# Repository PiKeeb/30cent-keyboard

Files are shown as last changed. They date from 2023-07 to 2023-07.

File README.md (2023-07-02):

# 30cent-keyboard





**30Cent** or **30₡** is a unique modular multi-layout ortholinear keyboard with *south-facing* MX sockets. It combines the functionalities of 30%, 40%, and 60% keyboards, allowing users to customize their layout. By removing the top and bottom rows, the keyboard can be transformed from a 5-row layout to a 4-row or 3-row layouts.Alternatively, users can keep the full layout intact to resemble a 60% keyboard, featuring a unique top row, that can be mounted either flat or at an angle.

The top row of the keyboard features two independent rotary encoders, eight function keys (or ten without the encoders), and a 0.91" I²C screen. The screen can be used to display various information, such as a WPM counter for typing speed.

The bottom row of the keyboard supports multiple space configurations. Users can choose between ultra-long options like 10U and 7U, or go with the standard 6.25U size. Additionally, there is a split configuration available, which consists of 1.50U + 2.25U + 2.25U + 1.50U.

Furthermore, the keyboard offers the flexibility to attach the top row at an angle using a FFC (Flexible Flat Cable), resulting in a truly unique and compact keyboard design.

## Features
- **Multi-layout Design**: Combines the functionalities of 30%, 40%, and 60% keyboards, allowing for versatile customization of the keyboard layout.
- **Breakable Top and Bottom Rows**: The ability to break off the top and bottom rows, transforming the keyboard from a forty-key layout to a thirty-key layout.
- **Unique Top Row**: Retains a unique top row even when the full layout is intact, providing a distinct design element.
- **Dual Rotary Encoders**: Supports two independent encoders on the top row for enhanced control and customization.
**Function Keys**: Features eight function keys (or ten without the knobs) for convenient access to additional commands.
**0.91" I²C Screen**: Top row includes a 0.91" I²C screen for displaying various information, such as a WPM counter for typing speed.
- **Multiple Space Configuration**s: Offers options for the bottom row space, including ultra-long configurations (10U and 7U), standard 6.25U, and a split configuration (1.50U + 2.25U + 2.25U + 1.50U). Additionally, users have the option to use two 2U keys as spaces if the bottom row is not being utilized.
- **Angled Top Row Attachment**: Provides the ability to attach the top row at an angle using a Flexible Flat Cable (FFC), resulting in a unique keyboard design.
- **MX Sockets**: Compatible with MX sockets, allowing for easy switch customization and replacement.
- **Optional Key Backlighting**: Offers the option for key backlighting, enhancing visibility and aesthetics in low-light environments.
- **Unique Breakable PCB Design**: The PCB is designed to be breakable, allowing for easy detachment and reattachment of top and bottom rows, facilitating customization of the keyboard layout.

## 3D CAD Renders

30CentRender 1
30CentRender 2
30CentRender 3
30CentRender 4

## Disclaimers

All the designs and files are provided **"AS IS"** without any warranty or support.

The designs are licensed under [**CC BY-SA 4.0 International Licence**](https://creativecommons.org/licenses/by-sa/4.0/)

**Warning!** This project has not been prototyped as of right now (working on it). Bear that in mind when doing anything with it.

## Project's Folder Structure

- `/case_files` contains the files related to the case design
- `/plate_files` contains the files related to the plate design
- `/pcb_files` contains the files related to the PCB design

Each subfolder contains `README.md` file that is useful to read if you'd like to produce or modify the project

## Acknowledgements

- PCB designed in [KiCad](https://www.kicad.org)
- Case designed and rendered in [Fusion360](https://www.autodesk.com/products/fusion-360/overview)
- The design inspired by Rotwitt's original [Modul concept/idea](https://media.discordapp.net/attachments/999745796532604949/1011554374352379954/SE.png)

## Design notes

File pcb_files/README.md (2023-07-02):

# 30cent-keyboard/pcb_files

## Folder Structure

- `/bom` contains the Bill of Material for PCB in interactive HTML format
- `/gerber` contains the Gerber files for PCB production
- `/kicad_project` contains the KiСad project files
- `/pcb_3dmodel` contains STEP 3D model of the PCB

**NB:** for opening the project files use the following version of KiCad (or newer):

*Version: 7.0.1-0, release build*

## PCB Revision History

REV  |  Description
--|--
1.0  |  Open-source Release version

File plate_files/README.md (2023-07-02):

# 30cent-keyboard/plate_files

## Folder Structure

- `/dxf` contains the DXF drawings of the key plates 
- `/step` contains STEP 3D models of the key plates

## Production instructions

All key plates have standart 1.5mm thickness.

`MidPlate` and `TopPlate` and `BotPlateCombined` are layout-agnostic. However, due to the location of stabilizer and switch holes, it's recommended to use `BotPlate*` tailored to your specific bottom row layout. If for example you'd like to use the **10U** spacebar, use the `BotPlate10.00u`.

You can omit the `BotPlate*` and/or the `TopPlate` if you don't plan to use bottom and/or top row(s).

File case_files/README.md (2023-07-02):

# 30cent-keyboard/case_files

## Production Instructions

### File Naming Convention

Due to modular nature, 30Cent keyboard has many parts. Each part corresponds to either the top, middle or bottom module of the keyboard.

`MiddleBody` is the center part of the assembly.

Parts that start with `Middle*` attach to the `MiddleBody` to form 30% layout.

Parts that start with `Top*` or `Bottom*` are used to attach the top and bottom rows respectively.

### Case Threads

ALL the threads on the case are standard M2.5. Threads should go inside the holes as deep as possible.

Thread locations for each part are below.

- MiddleBody
MiddleBodyT
MiddleBodyB

- TopBottom
TopAngle

- TopAngle
AngleTop

- TopTop
TopTop

- BottomTop
LongBottom

- MiddleTopSide x 2
MiddleTopSides

- MiddleUSBTop & MiddleBottomTop
MiddleUSBTopAndBottom

## Screw table

Below is the table containing all the screws needed for the assembly of the keyboard. 

Screw Type | Size | Length (mm) | McMaster P/N | Quantity
---------- | ---- | ----------- | ------------ | --------
ISO 14581  | M2.5 | 3	        | 90236A109    | 14
ISO 7380   | M2.5 | 6           | 92832A174    | 6
ISO 14581  | M2.5 | 10          | 90236A113    | 8
ISO 7380   | M2.5 | 12          | 92832A562    | 31

They are replacable with similar sized screws. 

**Warning!** When choosing similar screws, make sure that the nominal head diameter does exceed 4.7mm.

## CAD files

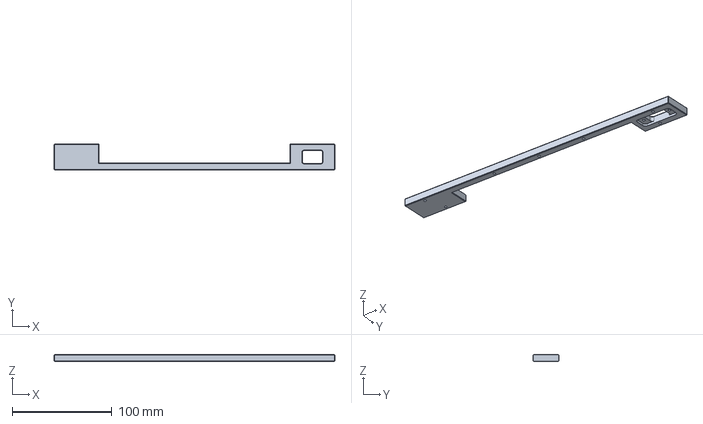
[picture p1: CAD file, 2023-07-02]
case_files/BottomTop.step
281.1 x 26.0 x 7.00 mm

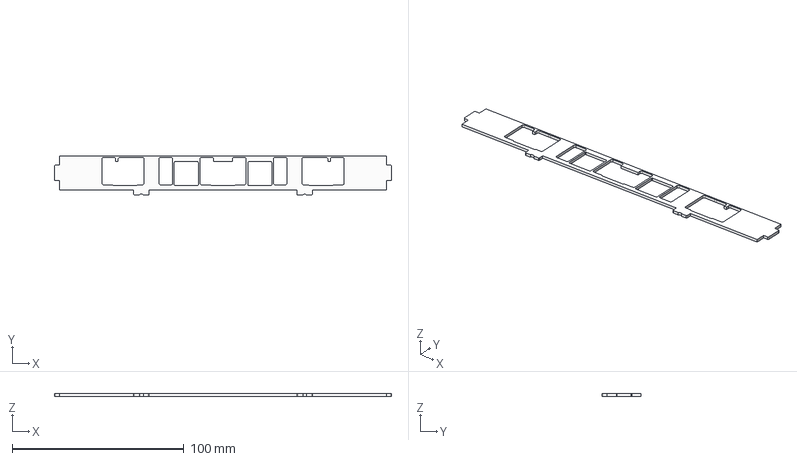
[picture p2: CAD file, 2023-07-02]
plate_files/step/BotPlateCombined.step
196.5 x 22.8 x 1.50 mm

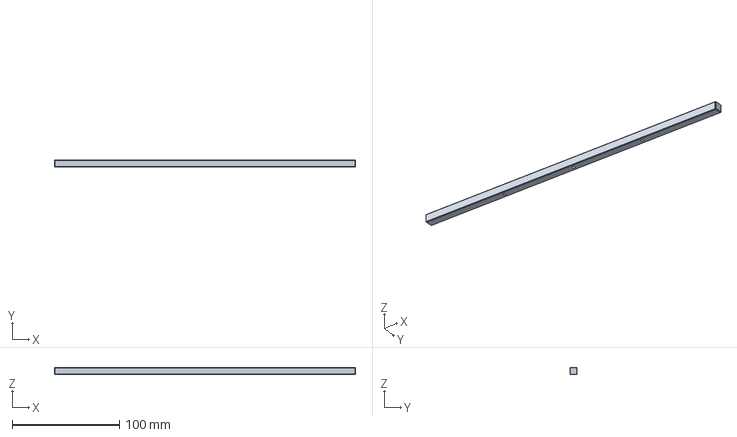
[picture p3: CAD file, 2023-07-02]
case_files/MiddleUSBTop.step
281.1 x 7.00 x 7.00 mm

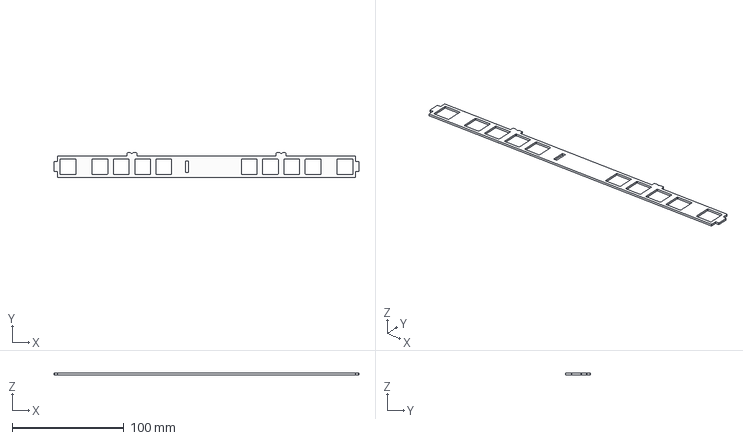
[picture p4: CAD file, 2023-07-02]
plate_files/step/TopPlate.step
272.7 x 22.0 x 1.50 mm

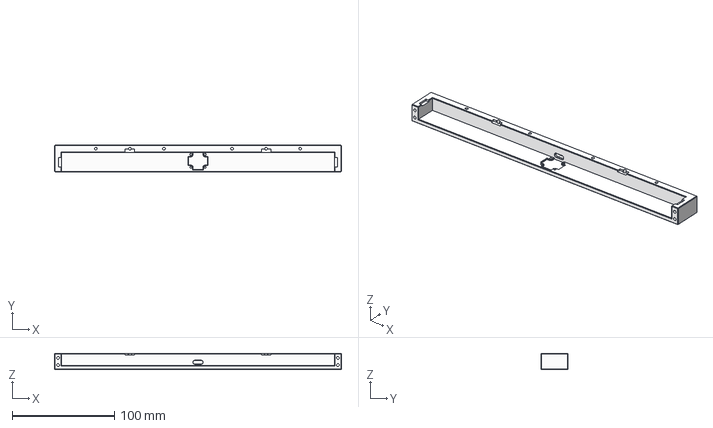
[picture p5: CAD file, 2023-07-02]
case_files/TopBottom.step
281.1 x 26.2 x 16.0 mm

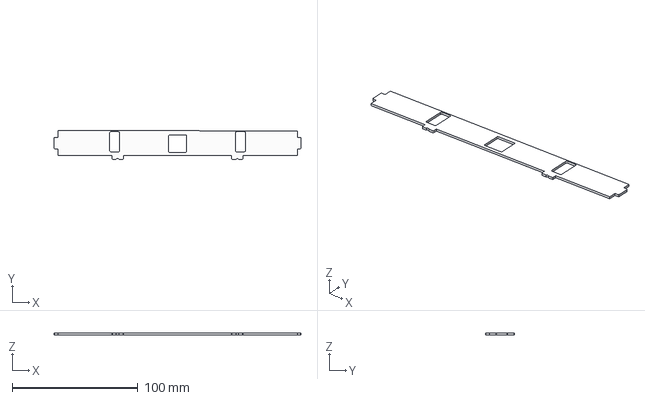
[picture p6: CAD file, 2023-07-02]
plate_files/step/BotPlate6.25u.step
196.5 x 22.8 x 1.50 mm

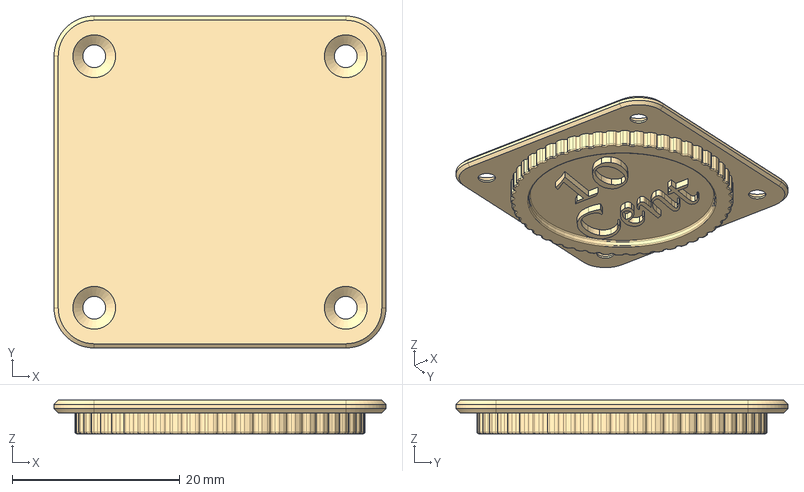
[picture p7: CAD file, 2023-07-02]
case_files/MiddleBadge.step
39.6 x 39.6 x 4.00 mm

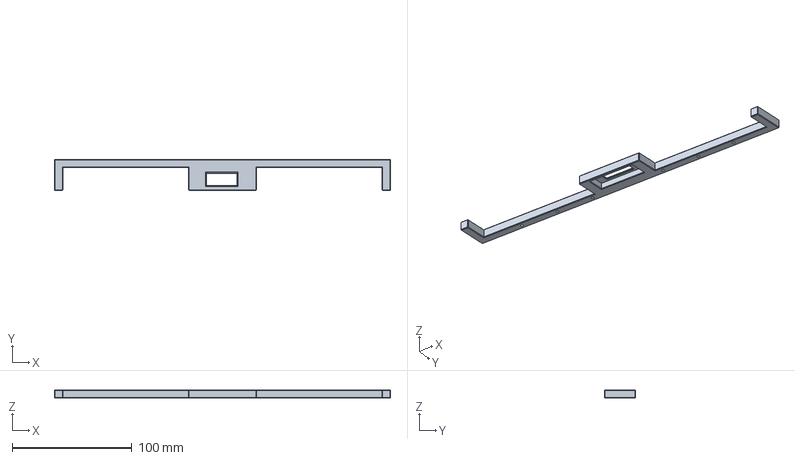
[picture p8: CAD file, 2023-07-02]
case_files/TopTop.step
281.1 x 26.2 x 7.00 mm

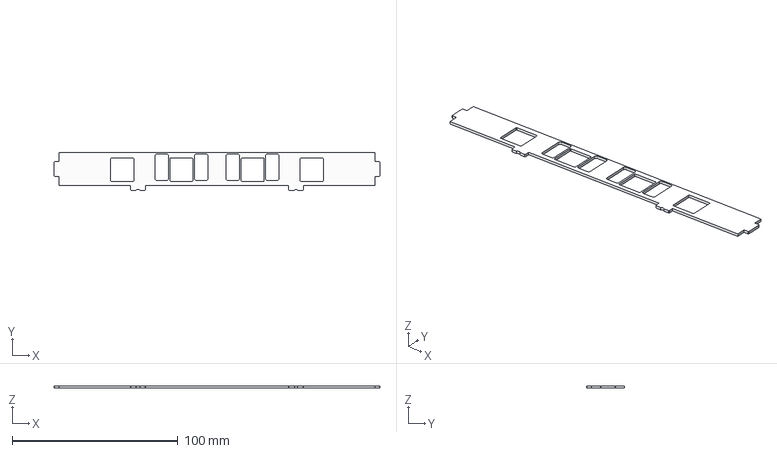
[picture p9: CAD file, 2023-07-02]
plate_files/step/BotPlateSplit.step
196.5 x 22.8 x 1.50 mm

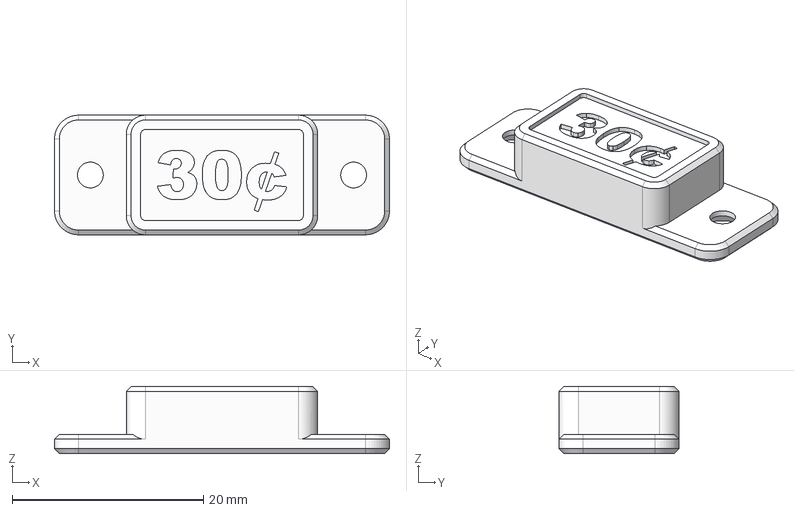
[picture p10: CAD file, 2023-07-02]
case_files/TopBadge.step
35.0 x 12.5 x 7.00 mm

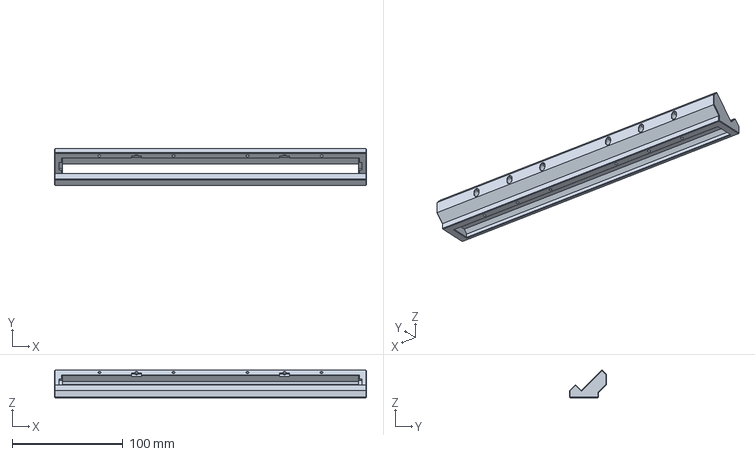
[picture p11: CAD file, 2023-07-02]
case_files/TopAngle.step
281.1 x 33.1 x 24.9 mm

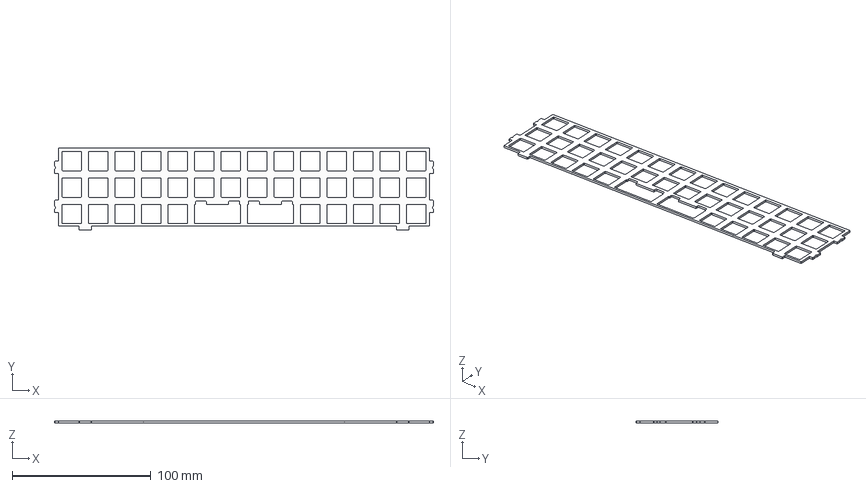
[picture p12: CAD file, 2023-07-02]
plate_files/step/MidPlate.step
272.7 x 59.1 x 1.50 mm

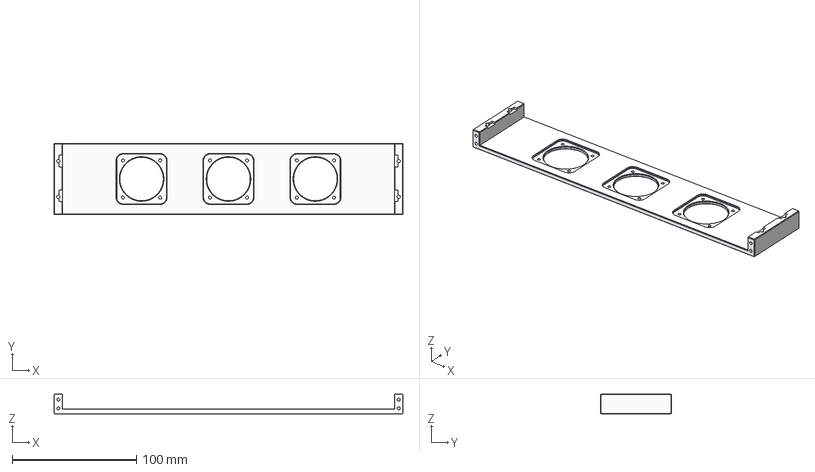
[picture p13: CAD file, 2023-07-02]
case_files/MiddleBody.step
281.1 x 57.5 x 16.0 mm

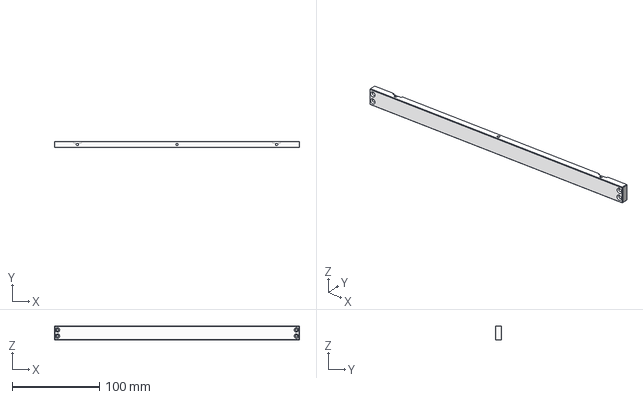
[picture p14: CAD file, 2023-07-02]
case_files/MiddleBot.step
281.1 x 7.00 x 16.0 mm

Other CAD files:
plate_files/step/BotPlate7.00u.step
plate_files/step/BotPlate10.00u.step
case_files/MiddleBottomTop.step
case_files/MiddleUSB.step
case_files/BottomBot.step
case_files/MiddleTopSide.step
plate_files/dxf/BotPlate10.00u.dxf
plate_files/dxf/BotPlate6.25u.dxf
plate_files/dxf/BotPlate7.00u.dxf
plate_files/dxf/BotPlateCombined.dxf
plate_files/dxf/BotPlateSplit.dxf
plate_files/dxf/MidPlate.dxf
plate_files/dxf/TopPlate.dxf

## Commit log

2023-07-02 case_files commit
    [BottomBot.step, BottomTop.step, MiddleBadge.step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]
2023-07-02 pcb_files commit
    [30cent-B_Cu.gbr, 30cent-B_Mask.gbr, 30cent-B_Paste.gbr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]
2023-07-02 plate_files commit
    [BotPlate10.00u.dxf, BotPlate10.00u.step, BotPlate6.25u.dxf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]
